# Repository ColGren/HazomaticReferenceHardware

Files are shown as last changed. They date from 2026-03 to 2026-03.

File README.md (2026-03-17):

# Hazomatic Reference Hardware Overview

Hazomatic Reference Hardware is a DIY reference implementation of the
Hazomatic particulate sensor protocol for ESP32-based devices.

This repository includes:
- Precompiled firmware (.bin)
- 3D-printable enclosure files
- Build documentation
- The Hazomatic protocol specification

This project is provided for experimental and educational use.
It is not a certified measurement instrument and is not intended for
regulatory, occupational health, or safety-critical applications.

Source code for the firmware is not included.

See LICENSE_FIRMWARE.txt, LICENSE_PROTOCOL.txt, LICENSE_DOCS.txt,
THIRD_PARTY_LICENSES.txt, and DISCLAIMER.md for full details.

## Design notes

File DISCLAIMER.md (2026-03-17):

Hazomatic Reference Hardware
Disclaimer and Limitation of Liability

This repository provides a reference implementation of the Hazomatic
sensor protocol, including compiled firmware, hardware enclosure files,
and build documentation.

This project is provided for experimental, educational, and DIY use only.

NO WARRANTY

The firmware, documentation, hardware designs, and all associated materials
are provided "AS IS", without warranty of any kind, express or implied,
including but not limited to warranties of merchantability, fitness for a
particular purpose, non-infringement, accuracy, or reliability.

NO CERTIFICATION

This project is not a certified measurement instrument.

It is not calibrated or approved for occupational health monitoring,
environmental compliance, regulatory reporting, or safety-critical use.

It must not be relied upon as the sole basis for health, safety, or
regulatory decisions.

ACCURACY AND PERFORMANCE

No representation is made regarding the accuracy, precision, or reliability
of measurements produced by the firmware or associated hardware.

Sensor readings may vary based on environmental conditions, assembly quality,
power supply stability, and other external factors.

DIY CONSTRUCTION RISK

This project involves user assembly of electronic components.

Users are solely responsible for:

- Safe electrical assembly
- Proper soldering and wiring
- Adequate power supply selection
- Mechanical integrity of enclosures
- Safe installation and operation

The author assumes no responsibility for damage, injury, loss, or
malfunction arising from construction or use of this project.

LIMITATION OF LIABILITY

To the fullest extent permitted by applicable law, the author shall not
be liable for any direct, indirect, incidental, special, consequential,
or punitive damages arising out of or related to the use of this project,
including but not limited to property damage, personal injury, loss of
profits, business interruption, regulatory penalties, or data loss.

COMMERCIAL AND VENUE USE

If this project is used in commercial venues, theatrical environments,
industrial settings, or public spaces, the user assumes full responsibility
for ensuring compliance with all applicable laws, regulations, and safety
requirements.

No endorsement, certification, or compliance status is implied.

Copyright 2026

Use of the HAZOMATIC name does not
imply certification or official product status.

By downloading, flashing, assembling, or using any materials in this
repository, you agree to these terms.

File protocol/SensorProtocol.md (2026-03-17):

# Hazomatic Sensor Protocol (Current Implementation - 16 Feb 2026)

This document describes the current on-device protocol expected by the Hazomatic Sensor app, based on the existing Swift implementation. It is not an idealized spec; it reflects what the app actually uses today.

## Overview

A sensor is expected to expose:

- HTTP endpoints on port 80 for basic JSON reads and identification.
- WebSocket endpoint on port 81 for streaming JSON readings and command control.

The app treats each sensor as a device with a unique ID, a location, and a network address. The data model is `SPS30Output`.

## Discovery (mDNS / Bonjour)

The app browses the local network for HTTP services and filters by instance name.

- Service type: `_http._tcp` in domain `local.`
- Instance name must start with `hazomatic` (case-insensitive).
- The app constructs the host as `<instanceName>.<domain>` (typically `hazomatic42.local`).
- The service is resolved to an IPv4 address and port using `NetService`.

If discovery succeeds, the app creates a `Sensor` with:

- `mDNSName`: the `<instanceName>.<domain>` host string
- `ipAddress`: the resolved IPv4 address
- `id`: the uuid from the sps30 or other sensor - this should not change, and must persist through sensor power cycles.

The advertised port is used only for tracking the discovered HTTP URL; the app still targets port 80 for HTTP and port 81 for WebSocket connections.

Note: The app triggers the local network permission prompt by opening a TCP connection to `hazomatic.local:8000` during discovery.

## Network Endpoints

### HTTP (port 80)

Base URL pattern (used for direct reads and ID lookups):

- `http://<ip>:80/selfclean`
- `http://<ip>:80/ip`

#### GET /selfclean

Triggers the sensor self-cleaning routine.

- Status code must be 2xx on success.
- Response body is currently ignored by the app.

#### GET /ip

Returns a JSON object with the sensor network identity.

Expected JSON shape (from `SensorID`):

```json
{
    "ip": "192.168.1.134",
    "host": "hazomatic42",
    "uuid": "SENSOR-UUID-STRING"
}
```

- Status code must be 2xx on success.
- The app extracts `uuid` and uses it as the sensor ID.

### WebSocket (port 81)

WebSocket URL pattern:

- `ws://<ip>:81/`

The WebSocket is used for:

- Receiving streaming sensor readings.
- Sending JSON command messages to the sensor.
- Keeping a heartbeat (the app sends WebSocket ping frames every 8 seconds).

The app considers the sensor online while the WebSocket is connected and ping/pong is healthy.

## Connection Lifecycle

1. Optional discovery via mDNS (see above).
2. Optional sensor ID lookup via `GET /ip` to retrieve a stable `uuid`.
3. WebSocket connection to `ws://<ip>:81/`.
4. App sends a JSON `{\"cmd\":\"ping\"}` and begins WebSocket ping frames.
5. Sensor pushes JSON readings over the socket or responds to `{\"cmd\":\"read\"}`.

## WebSocket Commands (App -> Sensor)

Commands are sent as JSON objects with a `cmd` field.

### Request a reading

```json
{ "cmd": "read" }
```

The sensor should respond by sending a reading JSON payload (see `SPS30Output`) over the WebSocket.

### Ping

```json
{ "cmd": "ping" }
```

This is an application-level ping (not the WebSocket ping frame). The app currently does not parse a response. You may ignore it or return a simple acknowledgment.

### Self-clean

```json
{ "cmd": "selfclean" }
```

Triggers sensor self-cleaning. The app does not parse the response; you may send a confirmation string or ignore.

## Reading Payload: SPS30Output

The app expects JSON matching this structure. This is used for:

- WebSocket streaming reads.
- HTTP `/read` responses.

### Expected JSON keys

```json
{
    "version": "1.0",
    "serial": "SENSOR-UUID-STRING",
    "pm1.0": 1.23,
    "pm2.5": 4.56,
    "pm4.0": 7.89,
    "pm10.0": 12.34,
    "nc0.5": 100.0,
    "nc1.0": 80.0,
    "nc2.5": 60.0,
    "nc4.0": 40.0,
    "nc10.0": 20.0,
    "typical_particle_size": 0.6
}
```

### Field notes

- `serial` is used as the sensor ID in the app.
- `pm1.0`, `pm2.5`, `pm4.0`, `pm10.0` map to mass concentration values.
- `nc0.5`, `nc1.0`, `nc2.5`, `nc4.0`, `nc10.0` map to number concentration values.
- `typical_particle_size` is a floating-point value.
- All numeric values are decoded as `Double`.

## Error Handling Expectations

The app treats the following as errors:

- Non-2xx HTTP status codes.
- Invalid or non-JSON responses.
- JSON that does not match the `SPS30Output` schema.

For WebSocket, messages that do not decode to `SPS30Output` are ignored, but their raw text may be logged for debugging.

## Timing and Retries

- WebSocket connect request timeout: 8 seconds.
- WebSocket heartbeat: ping frames every 8 seconds.
- Sensor ID lookup (`/ip`): up to 3 attempts with exponential backoff (1s, 2s, 4s; capped at 8s).
- HTTP requests use a 6-second timeout where explicitly set.

## Port Summary

- HTTP: port 80
- WebSocket: port 81

## Minimal Implementation Checklist

- HTTP GET `/read` returns valid `SPS30Output` JSON.
- HTTP GET `/ip` returns valid `SensorID` JSON with `uuid`.
- HTTP GET `/selfclean` returns 2xx.
- WebSocket endpoint accepts JSON commands and emits `SPS30Output` JSON.
- WebSocket responds to ping frames (standard WebSocket pong).

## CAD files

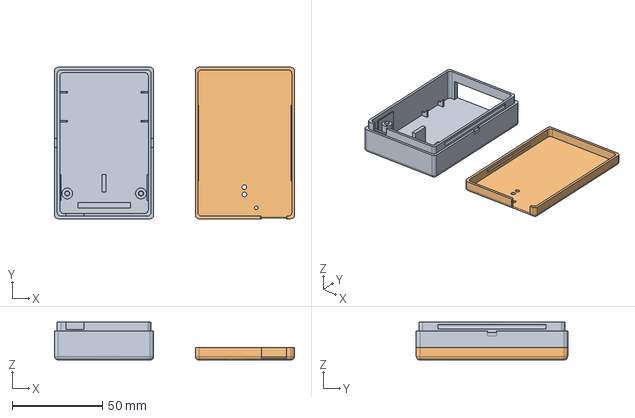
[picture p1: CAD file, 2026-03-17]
hardware/SuggestedBox.stp
133.0 x 84.0 x 21.0 mm

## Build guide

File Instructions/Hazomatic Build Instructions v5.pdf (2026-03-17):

© Colin Grenfell 2026 | 1 of 3

# Hazomatic Sensor Build:

Files needed:

For the case construction: .stp file in the hardware folder
To flash to the ESP32 board: .bin file in the firmware folder
NB: The .bin file only works for ESP32C3 board specified, please get in touch if you have questions.

# To buy:

SPS30 Sensirion sensor https://sensirion.com/company/news/press-releases-and-news/article/sensirion-inside-elv-pm25-particulate-matter-analyzer (https://sensirion.com/company/news/press-releases-and-news/article/sensirion-inside-elv-pm25-particulate-matter-analyzer)

I’ve been using Farnell as a supplier but lots of companies sell them.

An ESP32 C3 - for one that fits in the 3D printed enclosure and works with the .bin file, I’ve used this:

https://thepihut.com/products/baguette-c3-esp32-c3-prototyping-board?variant=54967506764161 (https://thepihut.com/products/baguette-c3-esp32-c3-prototyping-board?variant=54967506764161)

Get the board without headers.

And to connect the sensor to the board:

https://thepihut.com/products/jst-zh-cable-5-pin-1-5mm-pitch

Again there are lots of suppliers for this, but you might as well get the PiHut one if you’re ordering an esp32 from them.

A USB C power cable and power supply… The sensor does not need a beefy power supply.. probably whatever you have lying around! The sensor uses around 0.7 Watts whilst measuring data.

# Construction

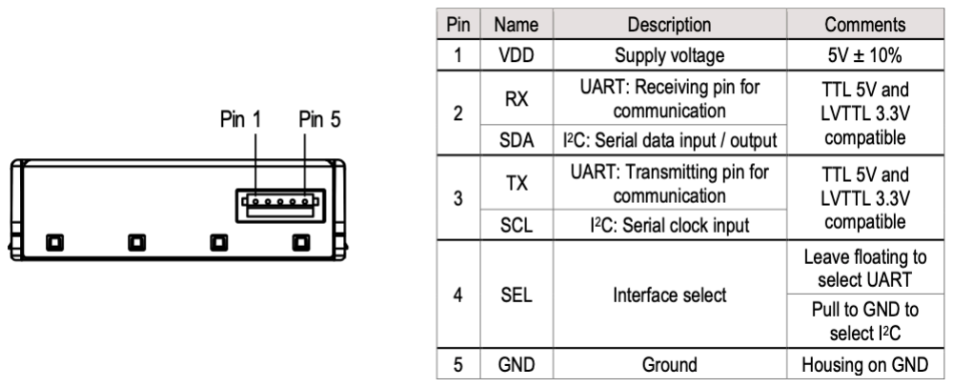
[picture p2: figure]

Plug in the connector to the sensor, then you need to solder 4 of the 5 cables to the board:

SPS30 Pin 1 5V to ESP32 5V SPS30 Pin 2 Rx to ESP32 Tx SPS30 Pin 3 Tx to ESP32 Rx SPS30 Pin 4 NOT USED
SPS30 Pin 5 to ESP32 Ground

# Flash the Firmware

I’ve made flashing simpler.. It’s a one time thing..

The firmware is the .bin file in the firmware folder
You will need a chrome based browser like Chrome, or Firefox - Safari will not work. Connect the usb lead to the sensor, then whilst plugging the usb lead into
your computer, hold down the bottom button on the sensor (you can release once it’s plugged in). This puts the sensor into flashing mode.

On your Chrome browser go to: https://adafruit.github.io/Adafruit_WebSerial_ESPTool/

When you connect you will be asked which USB port your sensor is connected to on the computer.

Next load the supplied .bin file onto the web page in the first slot..

Press Program and let the tool do its thing…
(about 30 seconds)

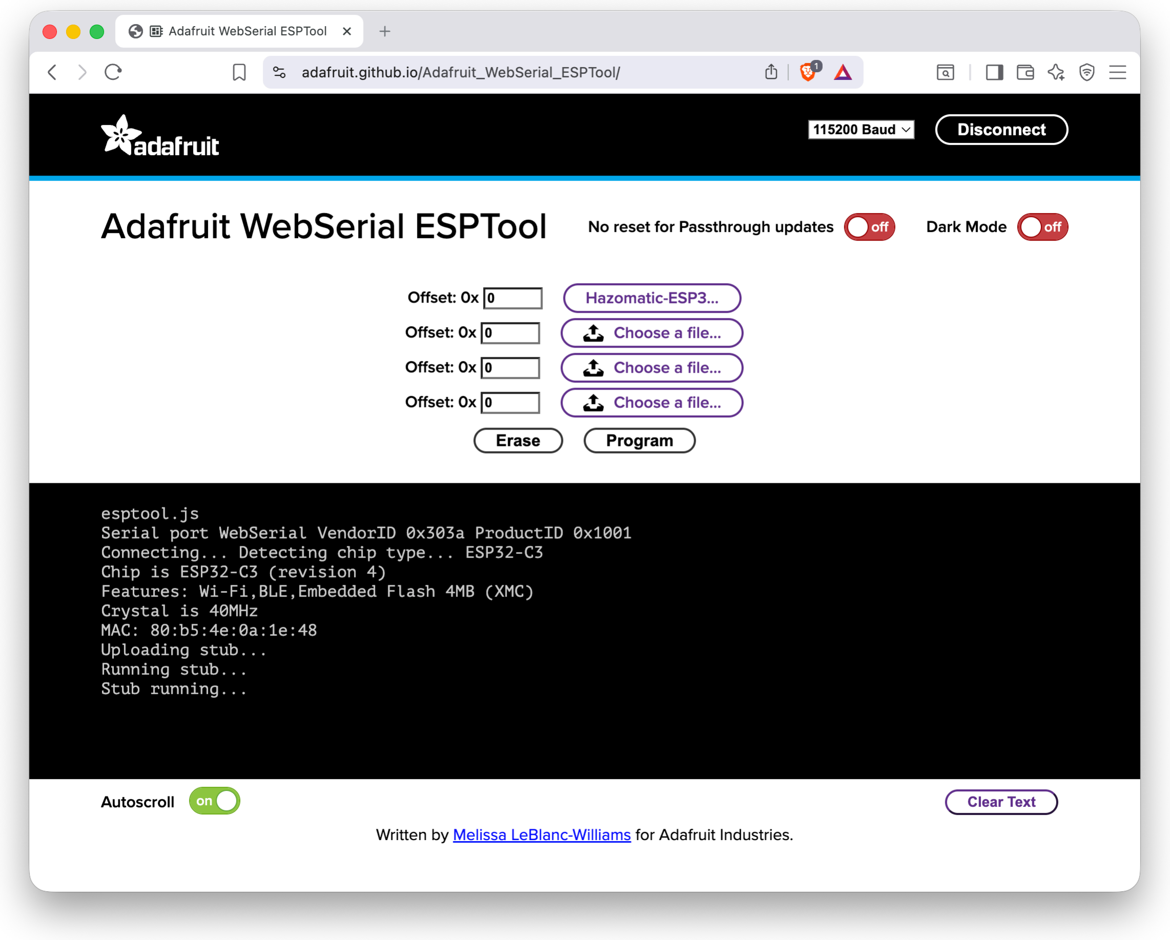
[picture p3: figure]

Once programmed you can press the bottom button (closest to the usb port) to restart, or remove and add to power… You don’t need to be connected to your computer anymore and flashing should be complete.

# Set up Hazomatic

Power up Hazomatic sensor, the LED will briefly flash, and then light amber.

To allow the sensor to join your local wifi network you need to put the sensor into wifi discovery mode do the following:

Power the device, by pushing then releasing the button at the bottom of the unit to restart it. Then within the next 10 seconds, push and hold the top button until the led light turns blue. This indicates the sensor is in wifi set up mode.

On a computer, phone or tablet, look at available networks - you should see the hazomatic SSID -join the network and a splash screen should shortly appear on your device.

Go to set up

Set the device to a unique number to your setup (only important if you are using more than one sensor. This sets the mDNS (bonjour) name to something like hazomatic45.local (the 45 being your number).

Press Save and you should return to the home screen.

Select Configure WiFi

Select your Wifi network or enter the SSID manually.

Enter the wifi password for your lx network. Hazomatic sensor should reboot and join the network. When it restarts up the led will be amber, when it connects to the wifi network the led turns green.

(If there is a problem with the Hazomatic sensor and it is unable to take measurements the led turns red - check your wiring!).

Go to the app and the sensors tab to add the sensor to Hazomatic app.

You should also be able to connect to the sensor via a very simple web interface using either the mDNS/bonjour name of your sensor http://hazomatic45.local or the direct ip address.
